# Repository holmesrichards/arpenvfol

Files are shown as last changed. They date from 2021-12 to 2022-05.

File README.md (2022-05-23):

# ARP Envelope follower

This is an envelope follower (EF) module in Kosmo format with mic and instrument preamplifiers.

It is a design based on the ARP 2600 — there’s a schematic in the [service manual](https://usermanual.wiki/Document/Arp2600ServiceManual.2176328765). Aside from changing the op amps to TL074 and reducing the output stage gain (which it seemed to need, maybe because it uses ±12 V instead of the ARP's ±15 V) the EF core is essentially identical to the original.

The ARP EF also has a preamplifier section for input of external, non-synth level signals which, of course, are what you’re going to use an EF on a lot of the time. Rather than try to adapt the Teledyne 1339 based design I replaced the ARP preamp with two different preamps: One to boost instrument levels to synth levels, and one to boost mic levels to instrument levels — which then goes through the other preamp as well. This is inspired by Eddie Bergman's [stripboard build](https://www.eddybergman.com/2020/02/synthesizer-build-part-20-arp2600.html), though I used different preamp circuits. The mic preamp is from a [design](http://www.zen22142.zen.co.uk/Circuits/Audio/ecmmic.htm) by Andy Collinson (with a mod from [here](https://electronics.stackexchange.com/questions/324047/%20what-is-the-best-preamplifier-circuit-for-electret-condenser-microphone)) while the instrument preamp is based on the one in Ken Stone’s [Stomp Box Adapter](https://sdiy.info/wiki/CGS_stomp_box_adapter_(smaller_version)). The mic preamp jack supplies power for a two terminal electret condenser mic. For a dynamic mic you may be able to use the instrument input, though I have not tested this.

If nothing’s plugged into the synth input it uses the output of the instrument preamp, and if nothing’s plugged into the input of the instrument preamp it uses the output of the mic preamp. And if nothing’s plugged into the input of the mic preamp it uses the condenser mic capsule mounted on the front panel! Yes, this module is always listening, so be careful what you say. Besides going to the EF input, the instrument preamp output goes to a front panel jack, so you can use this module to feed external signals (or the front panel mic) to other modules too.

This module isn't really a plug and play kind of thing. The output levels you get depend not only on the amplitude of the input signal but the waveform — square waves give bigger outputs than ramp waves, for instance. With an external signal source you will want to use the gain knob to get the preamp output up to around 10 Vpp, and then use the signal level knob to get the output to the right level. It's probably a good idea to use a scope to check your settings.

## Current draw
11.3 mA +12 V, 7.7 mA -12 V

## Photos

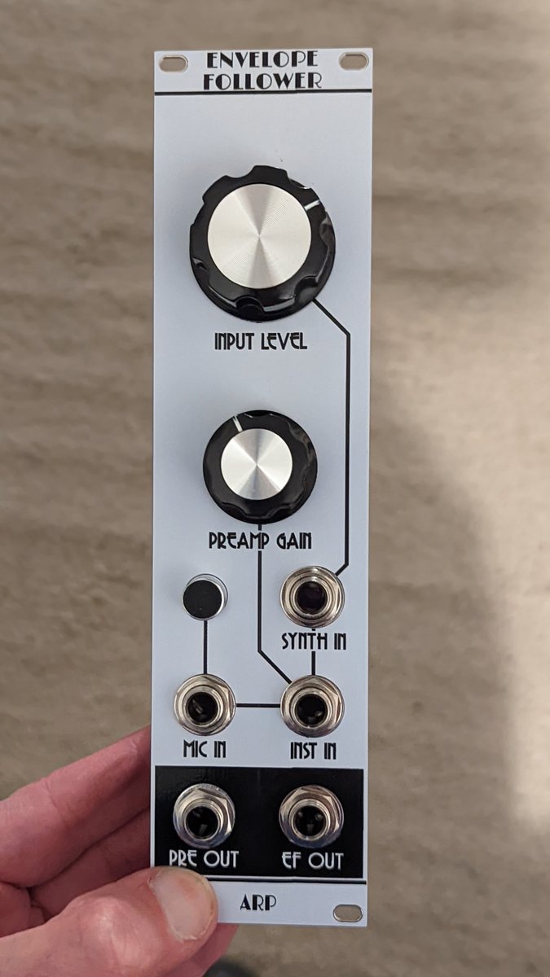
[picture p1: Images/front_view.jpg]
Front


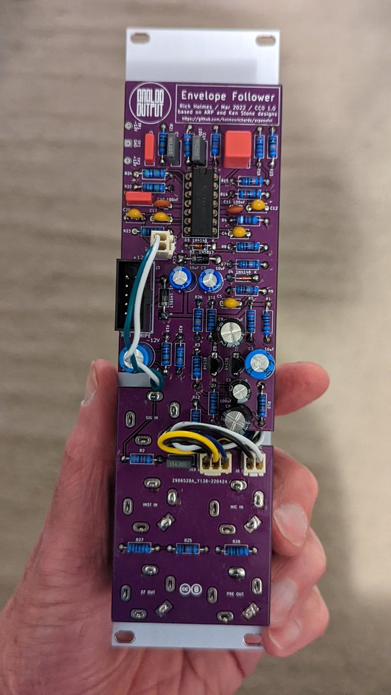
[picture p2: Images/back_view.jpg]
Back


## Documentation

* [Schematic](Docs/arpenvfol.pdf)
* PCB layout: [front](Docs/_layout_front.pdf), [back](Docs/_layout_back.pdf)
* [BOM](Docs/arpenvfol_bom.md)
* [Build notes](Docs/build.md)
* [Blog post](https://analogoutputblog.wordpress.com/2022/05/04/arp-2600-based-envelope-follower/)

## GitHub repository

* [https://github.com/holmesrichards/arpenvfol](https://github.com/holmesrichards/arpenvfol)

## Submodules

This repo uses submodules aoKicad and Kosmo_panel, which provide needed libaries for KiCad. To clone:

```
git clone git@github.com:holmesrichards/arpenvfol.git
git submodule init
git submodule update
```

Alternatively do

```
git clone --recurse-submodules git@github.com:holmesrichards/arpenvfol.git
```

Or if you download the repository as a zip file, you must also click on the "aoKicad" and "Kosmo\_panel" links on the GitHub page (they'll have "@ something" after them) and download them as separate zip files which you can unzip into this repo's aoKicad and Kosmo\_panel directories.

If desired, copy the files from aoKicad and Kosmo\_panel to wherever you prefer (your KiCad user library directory, for instance, if you have one). Then in KiCad, go into Edit Symbols and add symbol libraries 

```
aoKicad/ao_symbols
Kosmo_panel/Kosmo
```
and go into Edit Footprints and add footprint libraries 
```
aoKicad/ao_tht
Kosmo_panel/Kosmo_panel.
```

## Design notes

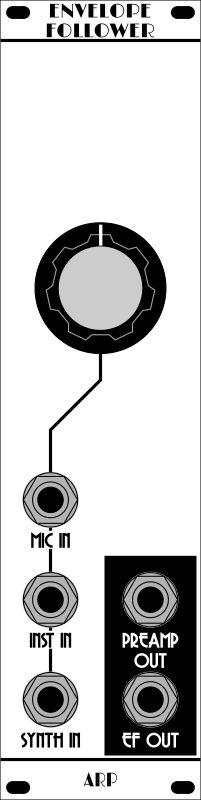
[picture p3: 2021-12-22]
Images/arpenvfol_panel.png

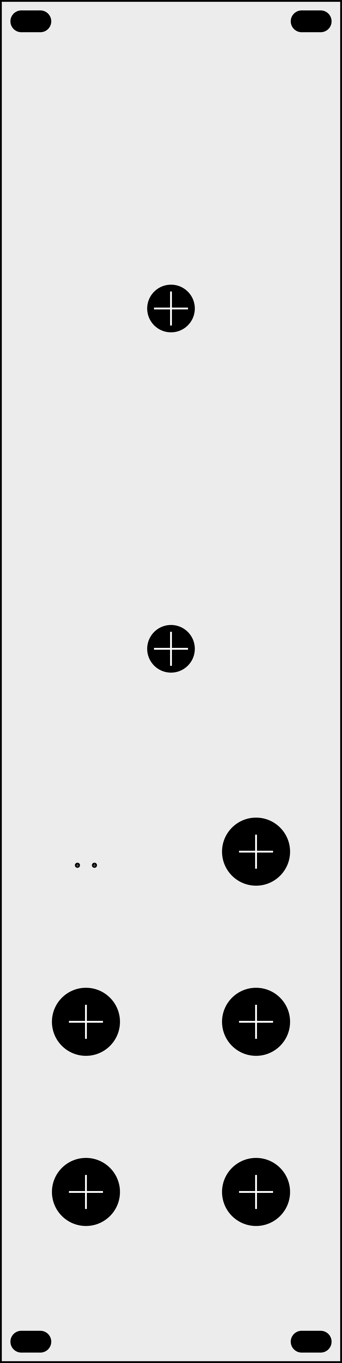
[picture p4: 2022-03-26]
Images/arpenvfol_panel_holes.png

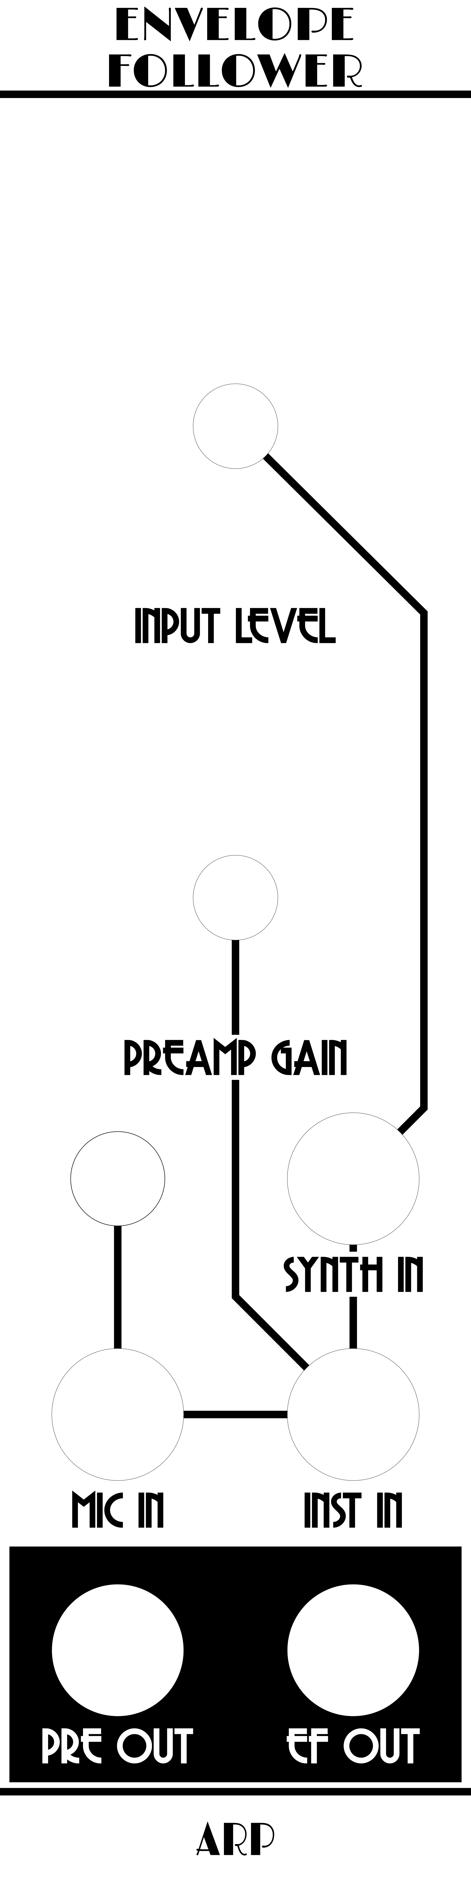
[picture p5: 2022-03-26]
Images/arpenvfol_panel_art.png

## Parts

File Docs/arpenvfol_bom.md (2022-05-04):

# arpenvfol.kicad_sch BOM

Wed 04 May 2022 04:19:42 PM EDT

Generated from schematic by Eeschema 6.0.4-6f826c9f35~116~ubuntu20.04.1

**Component Count:** 70

| Refs | Qty | Component | Description | Vendor | SKU |
| ----- | --- | ---- | --- | ---- | ---- |
| C1 | 1 | 100uF | Electrolytic capacitor, 2.5 mm pitch | Tayda | A-4538 |
| C2, C14 | 2 | 100nF | Polyester capacitor | Tayda | A-564 |
| C3, C15 | 2 | 10uF | Non polarized electrolytic capacitor, 3.5 mm pitch | Tayda | A-4216 |
| C4, C5, C12 | 3 | 20pF | Ceramic capacitor, 5 mm pitch | Tayda |  |
| C6, C7 | 2 | 10uF | Electrolytic capacitor, 2.5 mm pitch | Tayda | A-4349 |
| C8, C9 | 2 | 220uF | Electrolytic capacitor, 2.5 mm pitch | Tayda | A-1064 |
| C10, C11 | 2 | 100nF | Ceramic capacitor, 2.5 mm pitch | Tayda | A-553 |
| C13 | 1 | 1uF | Polyester capacitor | Tayda | A-4168 |
| C16 | 1 | 10nF | Polyester capacitor | Tayda | A-559 |
| C17 | 1 | 10pF | Ceramic capacitor, 5 mm pitch | Tayda |  |
| C18 | 1 | 2.2nF | Polyester capacitor | Tayda | A-558 |
| C19 | 1 | 47pF | Ceramic capacitor, 5 mm pitch | Tayda |  |
| C20 | 1 | 1nF | Polyester capacitor | Tayda | A-1531, A-557 |
| D1, D2 | 2 | 1N5817 | Schottky Barrier Rectifier Diode, DO-41 | Tayda | A-159 |
| D3, D4 | 2 | 1N4148 | Standard switching diode, DO-35 | Tayda | A-157 |
| J1, J2, J4 | 3 | AudioJack2_SwitchT | 1/4" jack, vertical, TR, switched | Tayda | A-1121 |
| J3 | 1 | Synth_power_2x5 | Pin header 2.54 mm 2x5 | Tayda | A-2939 |
| J5, J6 | 2 | 2_pin_Molex_connector | KK254 Molex connector | Tayda | A-826 |
| J7 | 1 | 3_pin_Molex_connector | KK254 Molex connector | Tayda | A-827 |
| J8, J9 | 2 | 2_pin_Molex_header | KK254 Molex header | Tayda | A-804 |
| J10 | 1 | 3_pin_Molex_header | KK254 Molex header | Tayda | A-805 |
| J11, J12 | 2 | AudioJack2 | 1/4" jack, vertical, TR | Tayda | A-1121 |
| MK1 | 1 | Microphone_Condenser | Condenser microphone | Tayda | A-5010 |
| Q1, Q2 | 2 | BC549 | 0.1A Ic, 30V Vce, Small Signal NPN Transistor, TO-92 | Tayda | A-111 |
| R1, R3, R11, R12, R27, R28 | 6 | 1k | Resistor, 1/4 W metal film | Tayda |  |
| R2 | 1 | 82k | Resistor, 1/4 W metal film | Tayda |  |
| R4 | 1 | 39k | Resistor, 1/4 W metal film | Tayda |  |
| R5 | 1 | 22k | Resistor, 1/4 W metal film | Tayda |  |
| R6, R10 | 2 | 10k | Resistor, 1/4 W metal film | Tayda |  |
| R7, R8, R9, R13, R15, R25, R26 | 7 | 100k | Resistor, 1/4 W metal film | Tayda |  |
| R14 | 1 | 120k | Resistor, 1/4 W metal film | Tayda |  |
| R16 | 1 | 2.7k | Resistor, 1/4 W metal film | Tayda |  |
| R17 | 1 | 27k | Resistor, 1/4 W metal film | Tayda |  |
| R18, R21 | 2 | 1M | Resistor, 1/4 W metal film | Tayda |  |
| R19 | 1 | 270k | Resistor, 1/4 W metal film | Tayda |  |
| R20 | 1 | 150k | Resistor, 1/4 W metal film | Tayda |  |
| R22 | 1 | 1.5M | Resistor, 1/4 W metal film | Tayda |  |
| R23 | 1 | 470R | Resistor, 1/4 W metal film | Tayda |  |
| R24 | 1 | 4.7M | Resistor, 1/4 W metal film | Tayda |  |
| RV1 | 1 | B10k | Linear potentiometer, panel mount | Tayda | A-1982 |
| RV2 | 1 | B100k | Linear potentiometer, panel mount | Tayda | A-1984 |
| U1 | 1 | TL074 | Quad operational amplifier, DIP-14 | Tayda | A-1138 |
| | 1 | | 14 pin DIP socket | | |

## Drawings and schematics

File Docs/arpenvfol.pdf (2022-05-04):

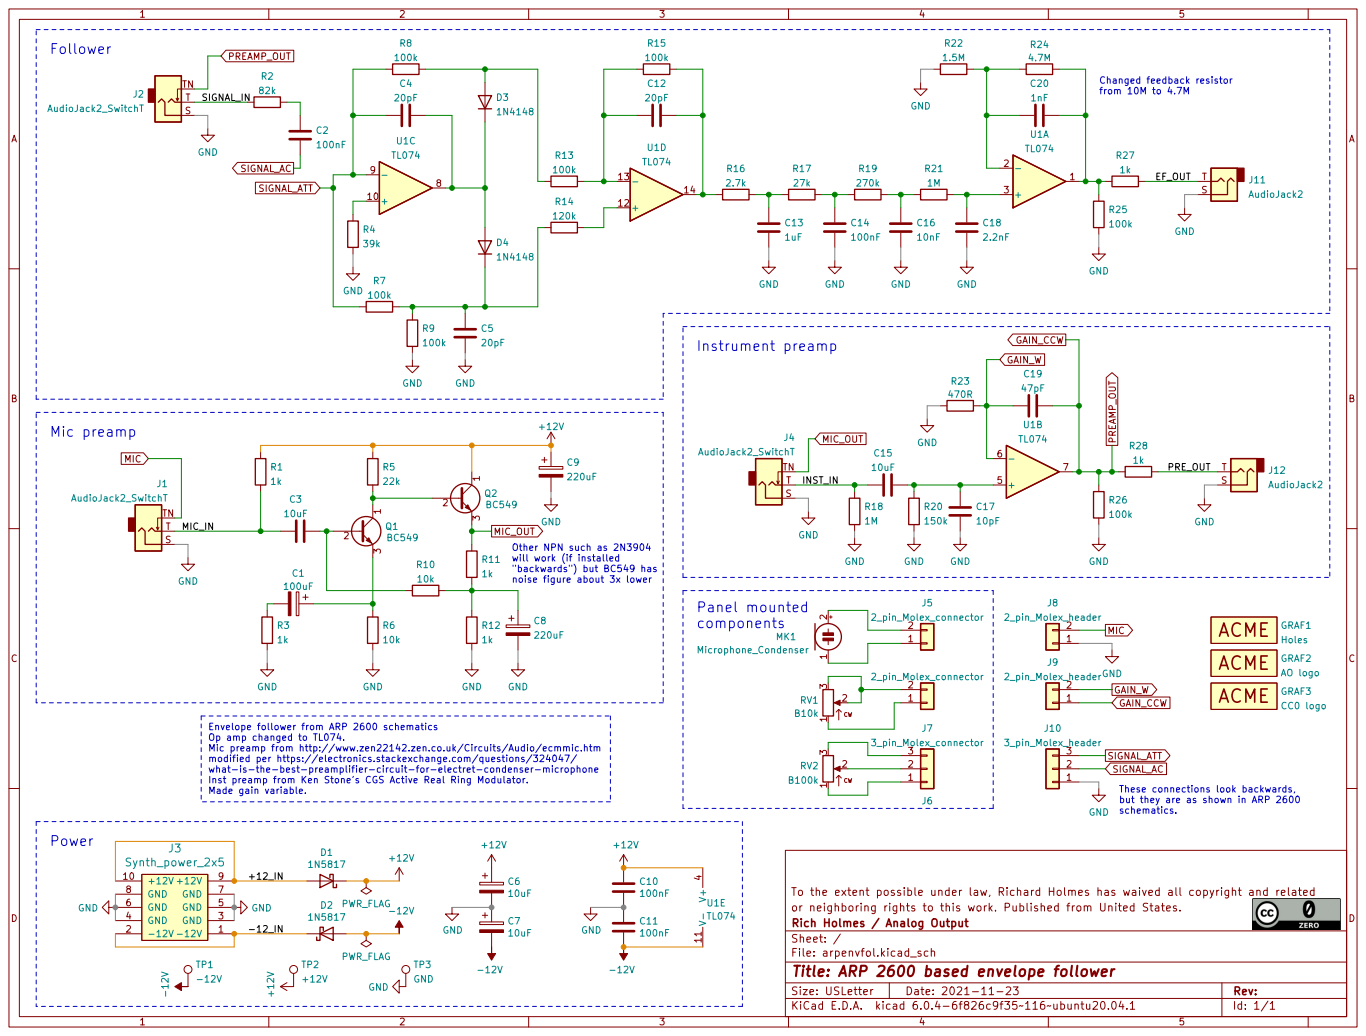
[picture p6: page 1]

components Other NPN such as 2N3904 will work (if installed
"backwards") but BC549 has
noise figure about 3x lower

To the extent possible under law, Richard Holmes has waived all copyright and related GND

Envelope follower from ARP 2600 schematics
Op amp changed to TL074.
Mic preamp from http://www.zen22142.zen.co.uk/Circuits/Audio/ecmmic.htm
modified per https://electronics.stackexchange.com/questions/324047/
what-is-the-best-preamplifier-circuit-for-electret-condenser-microphone
Inst preamp from Ken Stone's CGS Active Real Ring Modulator.
Made gain variable.

These connections look backwards, but they are as shown in ARP 2600

or neighboring rights to this work. Published from United States.
File: arpenvfol.kicad_sch Sheet: / Rich Holmes / Analog Output

Id: 1/1 Title: ARP 2600 based envelope follower

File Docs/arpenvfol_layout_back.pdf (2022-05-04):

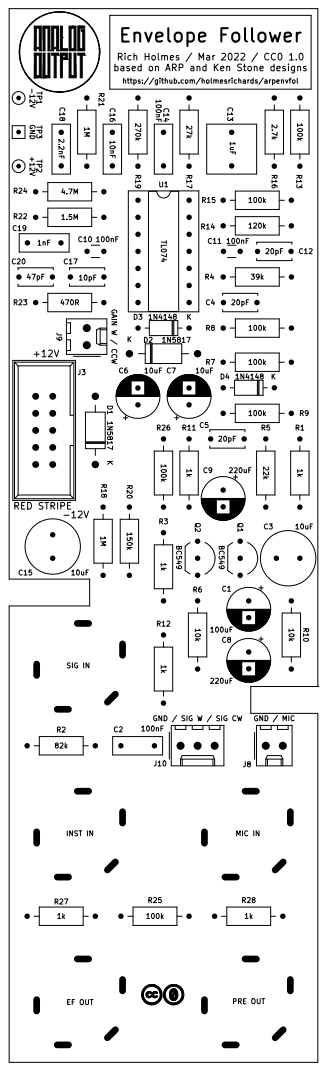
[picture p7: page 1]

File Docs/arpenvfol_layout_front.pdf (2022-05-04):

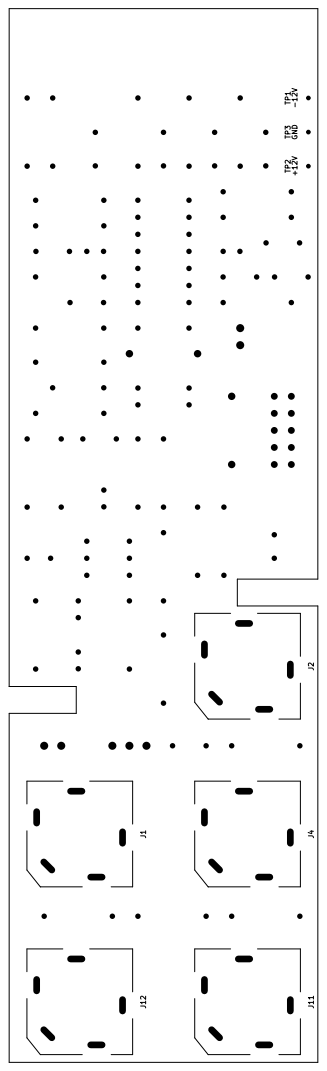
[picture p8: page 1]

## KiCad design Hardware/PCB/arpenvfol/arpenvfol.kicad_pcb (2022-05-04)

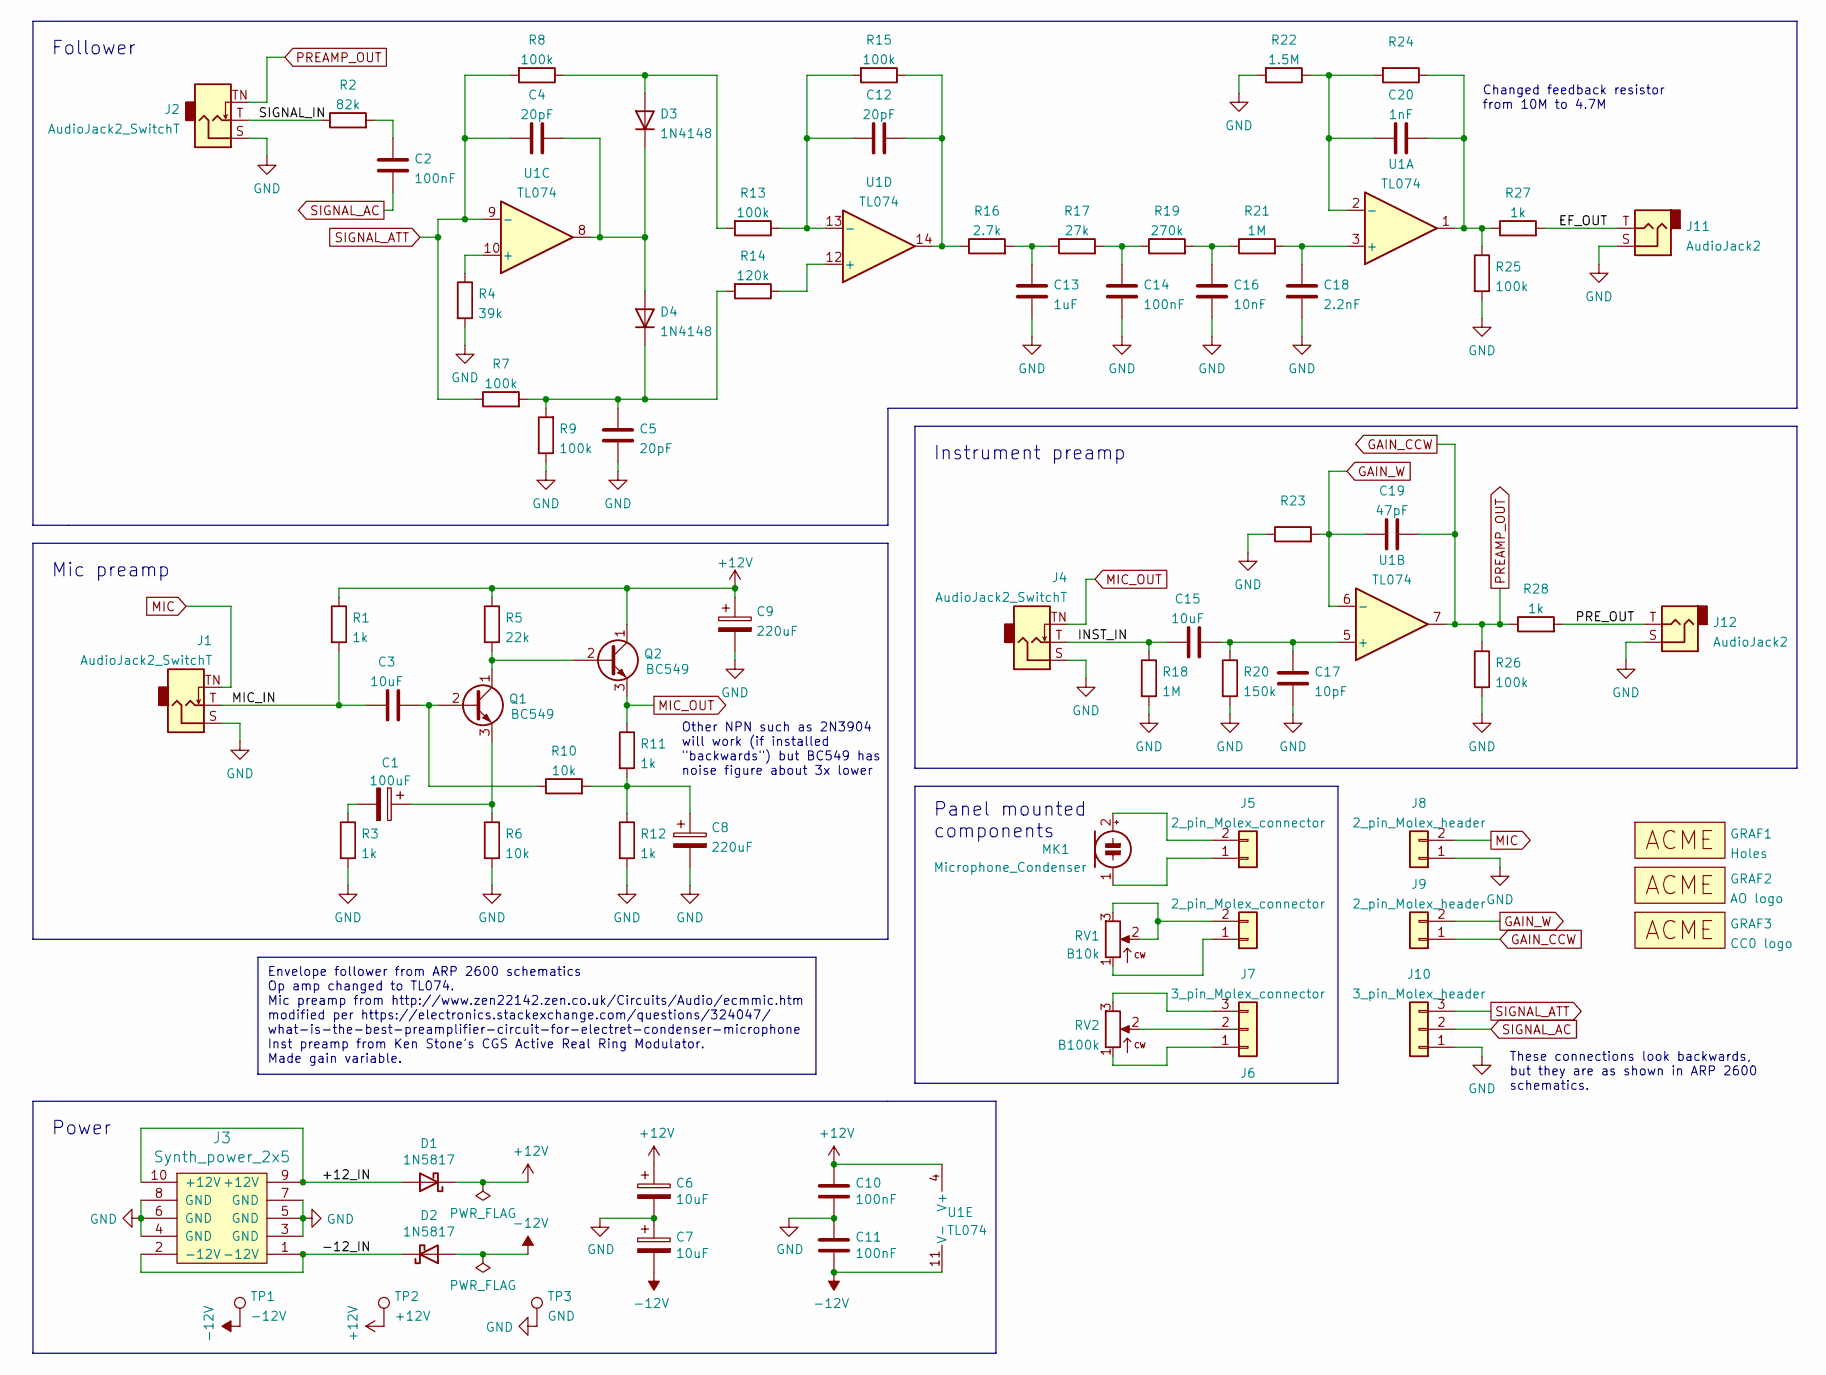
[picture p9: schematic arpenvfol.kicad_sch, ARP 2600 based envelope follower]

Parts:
C1: 100uF; CP_Radial_D6.3mm_P2.50mm
C2, C14: 100nF; C_Rect_L7.2mm_W2.5mm_P5.00mm_FKS2_FKP2_MKS2_MKP2
C3, C15: 10uF; C_Radial_D8.0mm_H11.5mm_P3.50mm
C4, C5, C12: 20pF; C_Disc_D5.0mm_W2.5mm_P5.00mm
C6, C7: 10uF; CP_Radial_D6.3mm_P2.50mm
C8, C9: 220uF; CP_Radial_D6.3mm_P2.50mm
C10, C11: 100nF; C_Disc_D3.0mm_W1.6mm_P2.50mm
C13: 1uF; C_Rect_L7.2mm_W7.2mm_P5.00mm_FKS2_FKP2_MKS2_MKP2
C16: 10nF; C_Rect_L7.2mm_W2.5mm_P5.00mm_FKS2_FKP2_MKS2_MKP2
C17: 10pF; C_Disc_D5.0mm_W2.5mm_P5.00mm
C18: 2.2nF; C_Rect_L7.2mm_W2.5mm_P5.00mm_FKS2_FKP2_MKS2_MKP2
C19: 47pF; C_Disc_D5.0mm_W2.5mm_P5.00mm
C20: 1nF; C_Rect_L7.2mm_W2.5mm_P5.00mm_FKS2_FKP2_MKS2_MKP2
D1, D2: 1N5817; D_DO-41_SOD81_P10.16mm_Horizontal
D3, D4: 1N4148; D_DO-35_SOD27_P7.62mm_Horizontal
GRAF1: Holes; arpenvfol_panel_holes
GRAF2: AO logo; analogoutput_12mm
GRAF3: CC0 logo; CC0_logo
J1, J2, J4: AudioJack2_SwitchT; Jack_6.35mm_PJ_629HAN_slots
J3: Synth_power_2x5; Power_Header
J5, J6: 2_pin_Molex_connector; Molex_KK-254_AE-6410-02A_1x02_P2.54mm_Vertical
J7: 3_pin_Molex_connector; Molex_KK-254_AE-6410-03A_1x03_P2.54mm_Vertical
J8, J9: 2_pin_Molex_header; Molex_KK-254_AE-6410-02A_1x02_P2.54mm_Vertical
J10: 3_pin_Molex_header; Molex_KK-254_AE-6410-03A_1x03_P2.54mm_Vertical
J11, J12: AudioJack2; Jack_6.35mm_PJ_629HAN_slots
MK1: Microphone_Condenser
Q1, Q2: BC549; TO-92_Inline_Wide
R1, R3, R11, R12, R27, R28: 1k; R_Axial_DIN0207_L6.3mm_D2.5mm_P10.16mm_Horizontal
R2: 82k; R_Axial_DIN0207_L6.3mm_D2.5mm_P10.16mm_Horizontal
R4: 39k; R_Axial_DIN0207_L6.3mm_D2.5mm_P10.16mm_Horizontal
R5: 22k; R_Axial_DIN0207_L6.3mm_D2.5mm_P10.16mm_Horizontal
R6, R10: 10k; R_Axial_DIN0207_L6.3mm_D2.5mm_P10.16mm_Horizontal
R7, R8, R9, R13, R15, R25, R26: 100k; R_Axial_DIN0207_L6.3mm_D2.5mm_P10.16mm_Horizontal
R14: 120k; R_Axial_DIN0207_L6.3mm_D2.5mm_P10.16mm_Horizontal
R16: 2.7k; R_Axial_DIN0207_L6.3mm_D2.5mm_P10.16mm_Horizontal
R17: 27k; R_Axial_DIN0207_L6.3mm_D2.5mm_P10.16mm_Horizontal
R18, R21: 1M; R_Axial_DIN0207_L6.3mm_D2.5mm_P10.16mm_Horizontal
R19: 270k; R_Axial_DIN0207_L6.3mm_D2.5mm_P10.16mm_Horizontal
R20: 150k; R_Axial_DIN0207_L6.3mm_D2.5mm_P10.16mm_Horizontal
R22: 1.5M; R_Axial_DIN0207_L6.3mm_D2.5mm_P10.16mm_Horizontal
R23, R24: R_Axial_DIN0207_L6.3mm_D2.5mm_P10.16mm_Horizontal
RV1: B10k
RV2: B100k
TP1: -12V; TestPoint_THTPad_D1.5mm_Drill0.7mm
TP2: +12V; TestPoint_THTPad_D1.5mm_Drill0.7mm
TP3: GND; TestPoint_THTPad_1.5x1.5mm_Drill0.7mm
U1: TL074; DIP-14_W7.62mm_Socket_LongPads

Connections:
+12V: C6.1, C9.1, C10.1, D1.1 (K), Q2.1 (C), R1.1, R5.1, TP2.1, U1.4 (V+)
-12V: C7.2, C11.2, D2.2 (A), TP1.1, U1.11 (V-)
/+12_IN: D1.2 (A), J3.9 (+12V), J3.10 (+12V)
/-12_IN: D2.1 (K), J3.1 (-12V), J3.2 (-12V)
/EF_OUT: J11.T, R27.2
/INST_IN: C15.1, J4.T, R18.1
/MIC_IN: C3.1, J1.T, R1.2
/PRE_OUT: J12.T, R28.2
/SIGNAL_IN: J2.T, R2.1
GAIN_CCW: C19.2, J2.TN, J9.1, R26.1, R28.1, U1.7
GAIN_W: C19.1, J9.2, R23.2, U1.6 (-)
GND: C5.2, C6.2, C7.1, C8.2, C9.2, C10.2, C11.1, C13.2, C14.2, C16.2, C17.2, C18.2, J1.S, J2.S, J3.3 (GND), J3.4 (GND), J3.5 (GND), J3.6 (GND), J3.7 (GND), J3.8 (GND), J4.S, J8.1, J10.1, J11.S, J12.S, R3.2, R4.2, R6.2, R9.1, R12.2, R18.2, R20.2, R22.2, R23.1, R25.2, R26.2, TP3.1
MIC: J1.TN, J8.2
MIC_OUT: J4.TN, Q2.3 (E), R11.1
unnamed: C1.1, Q1.3 (E), R6.1
unnamed: C1.2, R3.1
unnamed: C2.1, R2.2
unnamed: C3.2, Q1.2 (B), R10.1
unnamed: C4.2, D3.1 (K), D4.2 (A), U1.8
unnamed: C5.1, D4.1 (K), R7.2, R9.2, R14.2
unnamed: C8.1, R10.2, R11.2, R12.1
unnamed: C12.1, R13.1, R15.2, U1.13 (-)
unnamed: C12.2, R15.1, R16.1, U1.14
unnamed: C13.1, R16.2, R17.1
unnamed: C14.1, R17.2, R19.1
unnamed: C15.2, C17.1, R20.1, U1.5 (+)
unnamed: C16.1, R19.2, R21.1
unnamed: C18.1, R21.2, U1.3 (+)
unnamed: C20.1, R22.1, R24.2, U1.2 (-)
unnamed: C20.2, R24.1, R25.1, R27.1, U1.1
unnamed: D3.2 (A), R8.1, R13.2
unnamed: J5.1, MK1.1 (-)
unnamed: J5.2, MK1.2 (+)
unnamed: J6.1, RV1.1
unnamed: J6.2, RV1.2, RV1.3
unnamed: J7.1, RV2.1
unnamed: J7.2, RV2.2
unnamed: J7.3, RV2.3
unnamed: Q1.1 (C), Q2.2 (B), R5.2
unnamed: R4.1, U1.10 (+)
unnamed: R14.1, U1.12 (+)
SIGNAL_AC: C2.2, J10.2
SIGNAL_ATT: C4.1, J10.3, R7.1, R8.2, U1.9 (-)

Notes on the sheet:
Follower
Other NPN such as 2N3904 will work (if installed "backwards") but BC549 has noise figure about 3x lower
Power
These connections look backwards, but they are as shown in ARP 2600 schematics.
Instrument preamp
Panel mounted components
Changed feedback resistor from 10M to 4.7M
Envelope follower from ARP 2600 schematics Op amp changed to TL074. Mic preamp from http://www.zen22142.zen.co.uk/Circuits/Audio/ecmmic.htm modified per https://electronics.stackexchange.com/questions/324047/ what-is-the-best-preamplifier-circuit-for-electret-condenser-microphone Inst preamp from K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
Mic preamp

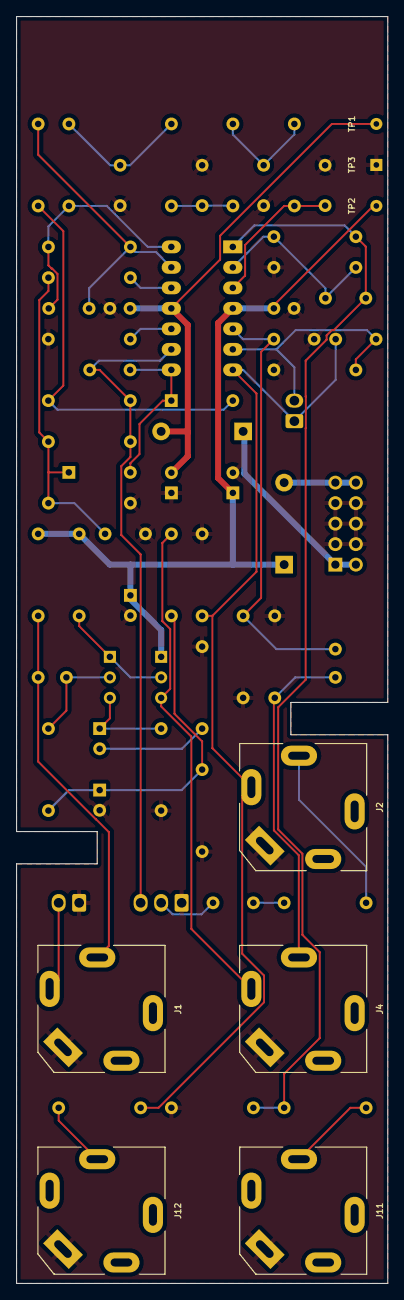
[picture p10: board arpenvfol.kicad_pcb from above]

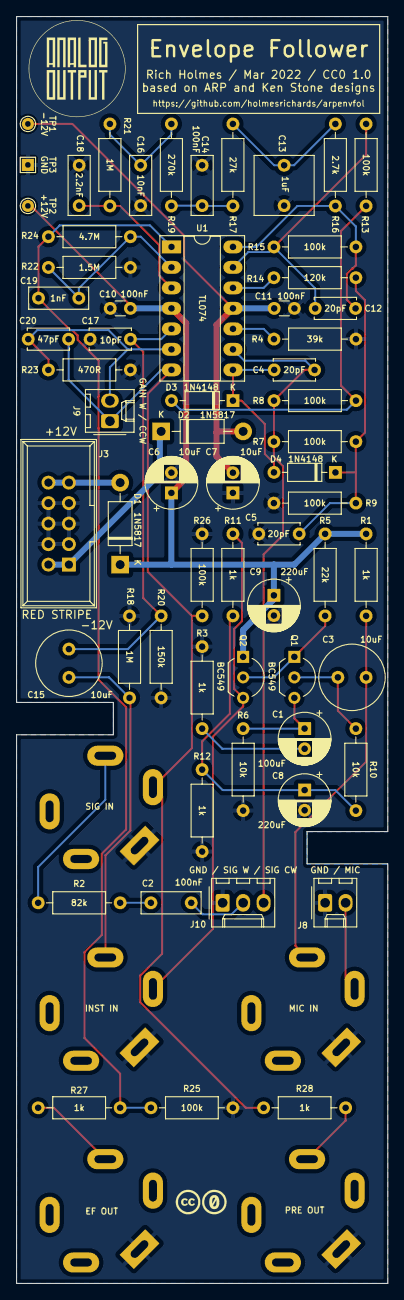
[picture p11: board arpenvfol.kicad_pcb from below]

Board: 2 copper layers, 46.0 x 157.0 mm, 70 parts (64 on the bottom side), 36 nets.

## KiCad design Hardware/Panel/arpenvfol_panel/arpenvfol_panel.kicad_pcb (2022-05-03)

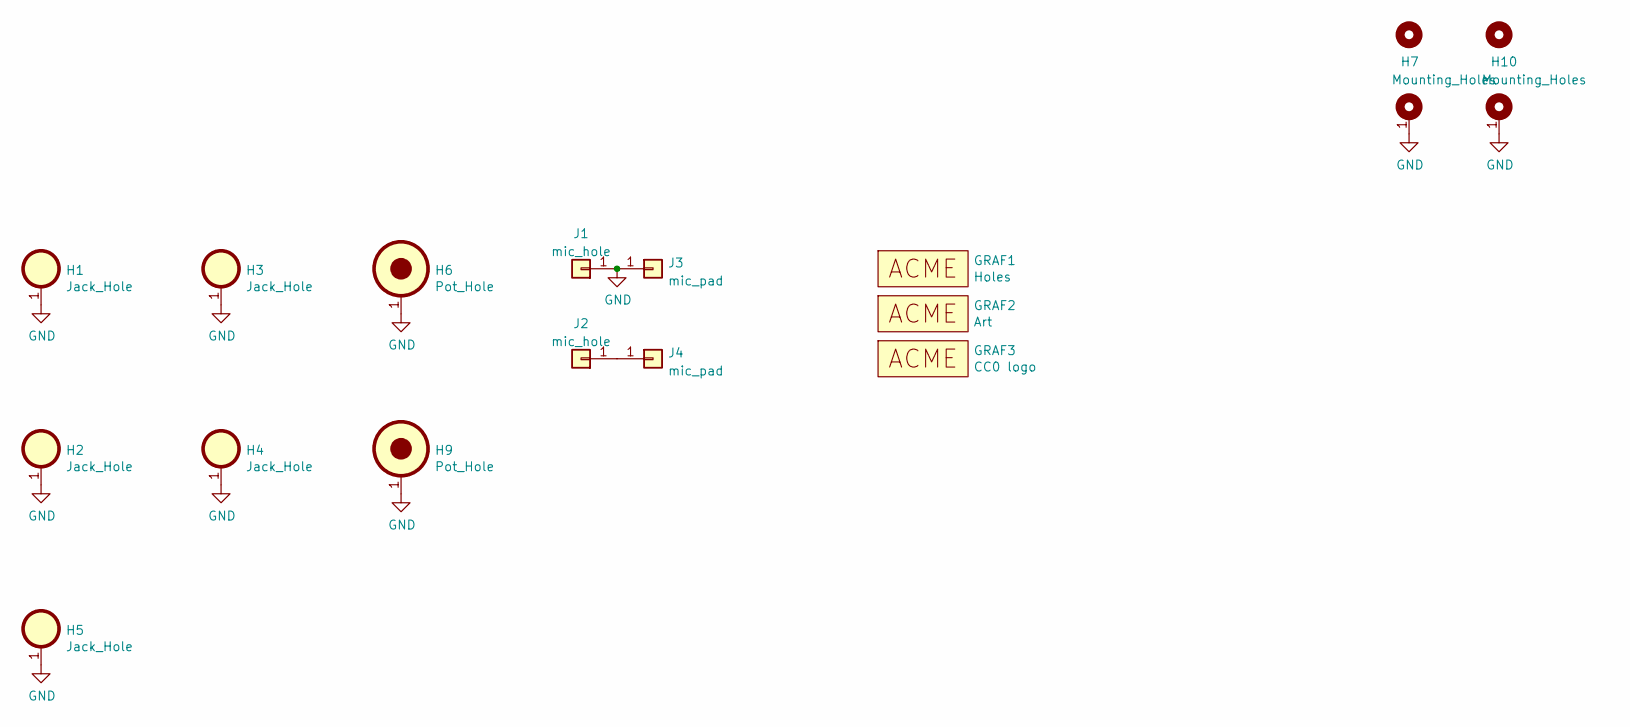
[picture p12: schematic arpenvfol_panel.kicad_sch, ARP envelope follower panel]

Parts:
GRAF1: Holes; arpenvfol_panel_holes
GRAF2: Art; arpenvfol_panel_art
GRAF3: CC0 logo; CC0_logo
H1, H2, H3, H4, H5: Jack_Hole; Kosmo_Jack_Hole
H6, H9: Pot_Hole; Kosmo_Pot_Hole
H7, H10: Mounting_Holes; Kosmo_Panel_Dual_Slotted_Mounting_Holes
J1: mic_hole; TestPoint_THTPad_1.5x1.5mm_Drill0.7mm
J2: mic_hole; TestPoint_THTPad_D1.5mm_Drill0.7mm
J3, J4: mic_pad; TestPoint_Pad_D4.0mm

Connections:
GND: H1.1, H2.1, H3.1, H4.1, H5.1, H6.1, H7.1, H9.1, H10.1, J1.1, J3.1
unnamed: J2.1, J4.1

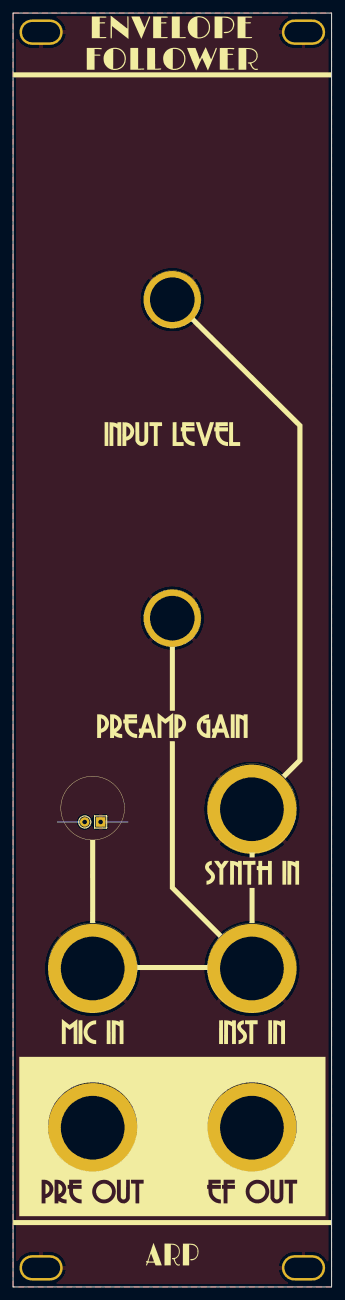
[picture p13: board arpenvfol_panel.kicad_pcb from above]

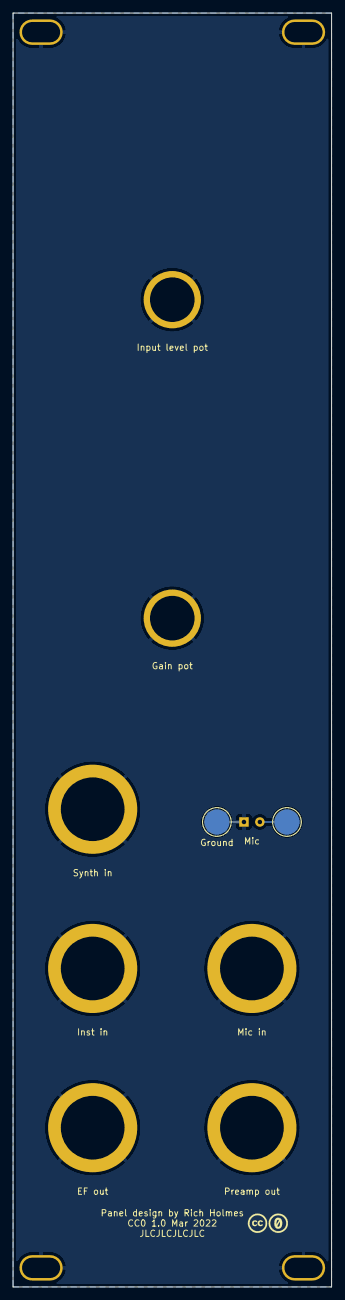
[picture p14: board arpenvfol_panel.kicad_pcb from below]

Board: 2 copper layers, 50.0 x 200.0 mm, 16 parts (3 on the bottom side), 2 nets.

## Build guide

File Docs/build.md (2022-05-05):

# ARP Envelope follower build notes

## ERRATA

In the first PCB run R23 was 1k and R24 was 3M. I recommend the following resistor value changes, which will increase the maximum gain and output level:

* R23 from 1k to 470R
* R24 from 3M to 4.7M

These values were changed in the design files after the first run.

## Building

There's almost nothing to note about the build; it's very standard aside from one thing. A condenser mic capsule is mounted directly to the front panel. Solder its leads to the through hole pads provided. Then put blobs of solder on the surface pads on the back of the panel and solder stranded wire leads to those pads. I added hot glue on top of these pads to strengthen the mechanical connection. Connect these wires to the mic Molex header on the PCB (or solder directly).

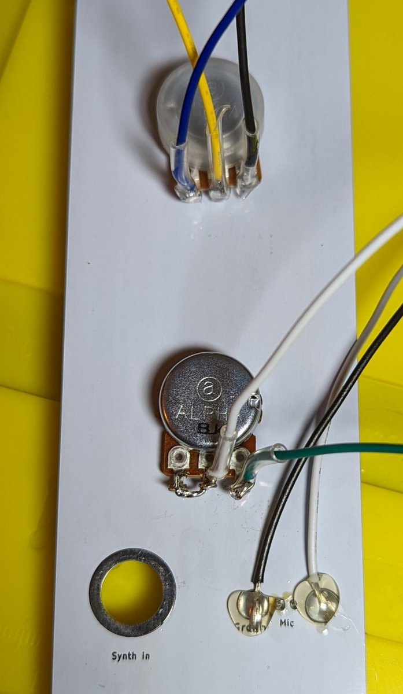
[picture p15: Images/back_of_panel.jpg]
back_of_panel


As shown, pins 2 and 3 of the gain pot are connected together, with the other two pins connected to the gain Molex header on the PCB. The other pot has all three pins connected to the PCB. Labels on the PCB indicate pin 1 (counter clockwise, CCW, as seen from the front of the panel), 2 (wiper, W), and 3 (clockwise, CCW). Note wire colors:

back_view

## Adjust to taste

Modules that interface to external signals may be the most subjective designs of all. You may want larger or smaller gains. To increase the gain of the preamplifier decrease the value of R23 (or increase the value of the pot). To increase the output signal increase the value of R24 (or decrease the value of R22).

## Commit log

2021-11-24 Initial version
    [arpenvfol.kicad_pcb, arpenvfol.kicad_sch, mainpcb.kicad_sch]
2021-11-24 rm cap, add mic
    [arpenvfol.kicad_sch, mainpcb.kicad_sch]
2021-11-25 Update pot symbols
    [arpenvfol.kicad_sch, mainpcb.kicad_sch]
2021-12-05 README edit; design updates; panel art
    [arpenvfol.kicad_pcb, arpenvfol.kicad_sch, mainpcb.kicad_sch]
2021-12-22 NP electrolytics; revise panel
    [arpenvfol.kicad_sch, mainpcb.kicad_sch]
2022-02-01 Better .gitignore; misc revisions
    [arpenvfol.kicad_pcb, arpenvfol.kicad_sch, mainpcb.kicad_sch]
2022-02-14 Reorganize schem; add resistor to mic preamp; change EF gain; add simulation
    [arpenvfol.kicad_pcb, arpenvfol.kicad_sch, mainpcb.kicad_sch]
2022-03-07 Change transistor, annotate, LTSpice simulation
    [arpenvfol.kicad_pcb, arpenvfol.kicad_sch]
2022-03-26 Panel; add gain pot
    [arpenvfol.kicad_pcb, arpenvfol.kicad_sch, arpenvfol_panel.kicad_pcb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]
2022-04-03 schem tweak
    [arpenvfol_panel.kicad_sch]
2022-04-11 Schem reorg
    [arpenvfol.kicad_sch]
2022-05-03 Final pre fab tweaks, Gerbers, schematic, BOM
    [arpenvfol-CmtUser.gbr, arpenvfol-CuBottom.gbl, arpenvfol-CuTop.gtl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]
2022-05-04 Change 2 resistor values
    [arpenvfol.kicad_sch]
2022-05-04 Revert "Change 2 resistor values"
    This reverts commit a172cd43ee9637b883d7b4f7545da2461ae37f05.
    [arpenvfol.kicad_sch]
2022-05-04 Update PCB, layout files
    [arpenvfol.kicad_pcb]
2022-05-05 Updated PCB Gerbers
    [arpenvfol-CmtUser.gbr, arpenvfol-CuBottom.gbl, arpenvfol-CuTop.gtl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]
2022-05-23 Current draw

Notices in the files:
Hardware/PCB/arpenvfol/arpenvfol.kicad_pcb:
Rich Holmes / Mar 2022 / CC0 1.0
